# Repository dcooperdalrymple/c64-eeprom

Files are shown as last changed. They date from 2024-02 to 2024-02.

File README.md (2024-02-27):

# C64-EEPROM



Use standard 0.6" DIP EEPROMs in place of a mask rom footprints. Compatible with various mask roms and EEPROMS with solder jumper configuration.

| Top | Bottom |
| --- | --- |
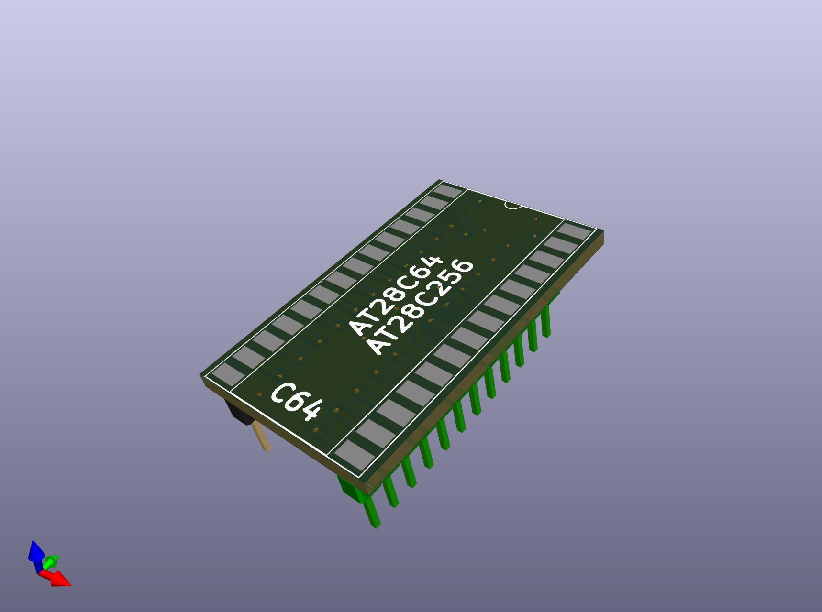
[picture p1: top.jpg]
Top view of the adapter board
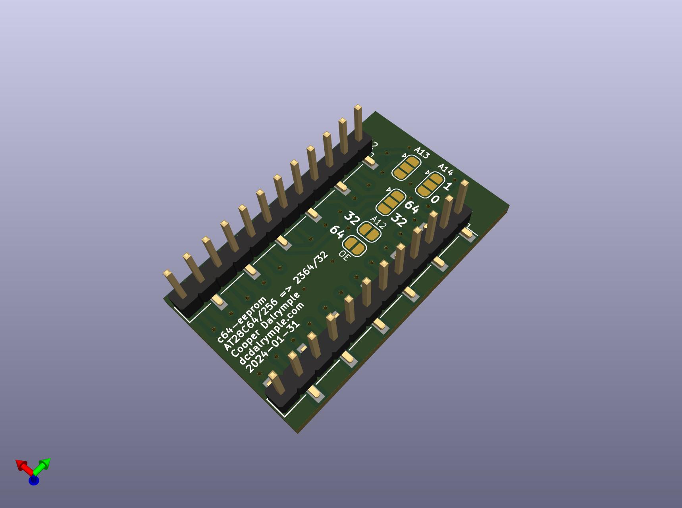
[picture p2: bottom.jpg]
Bottom view of the adapter board
|  |  |

## Compatible ROM ICs

Use the following tables to determine the necessary solder jumper configuration.

### EEPROMs

| EEPROM | Configuration |
| --- | --- |
| AT28C64(B)  | A13 and A14 jumpers can be left unconfigured (NC). |
| AT28C256 | A13 and A14 jumpers can be configured to select 1 of 4 banks. Leave both as "0" (GND) to use first 4/8KB. |

> It is possible to connect switches to the A13 and A14 solder jumper pads to enable quick bank switching with an AT28C256 to select between 4 ROM images. To minimize size and materials, this board does not include this feature by default.

### Mask ROMs

| Mask ROM | Typical Usage | Configuration |
| --- | --- | --- |
| 2364 | C64 Kernal (901227-03) & BASIC (901226-01) ROMs | Solder pad 2 (middle) to pad 1 (arrow) of the 64/32 jumper (the 64 side) and the OE jumper. |
| 2332 | C64 Character ROM (901225-01) | Solder pad 2 (middle) to pad 3 (bottom) of the 64/32 jumper (the 32 side) and the A12 jumper. |

## Materials

This board uses 2 SMD 0.1" pitch pin headers and 1 0.6" wide, 0.1" pitch SMD DIP socket. SMD components were selected to reduce board width. However, standard through hole components can be easily modified to be SMD compatible by bending the socket legs outward and the pin header legs left and right alternating outward.

No other components are necessary as the AT28C64/256 EEPROMS are 5V-compatible and otherwise identical to standard mask roms. Using this board without an IC socket for the EEPROM is possible, but not recommended.

## Programming

EEPROMs are fairly simple and easy to program. They can be programmed using a standard TL866 programmer or any other compatible ROM programmer. A number of other solutions also exist which don't require specialized equipment. Here are a few options using off-the-shelf components:

- [PicoPROM](https://github.com/gfoot/picoprom)
- [32u4-programmer](https://github.com/dcooperdalrymple/32u4-programmer) (a little bit of self-promotion here)
- [Arduino EEPROM programmer](https://github.com/beneater/eeprom-programmer)
- [eeprom-writer](https://github.com/oddblk/eeprom-writer)
- [TommyPROM](https://tomnisbet.github.io/TommyPROM/)

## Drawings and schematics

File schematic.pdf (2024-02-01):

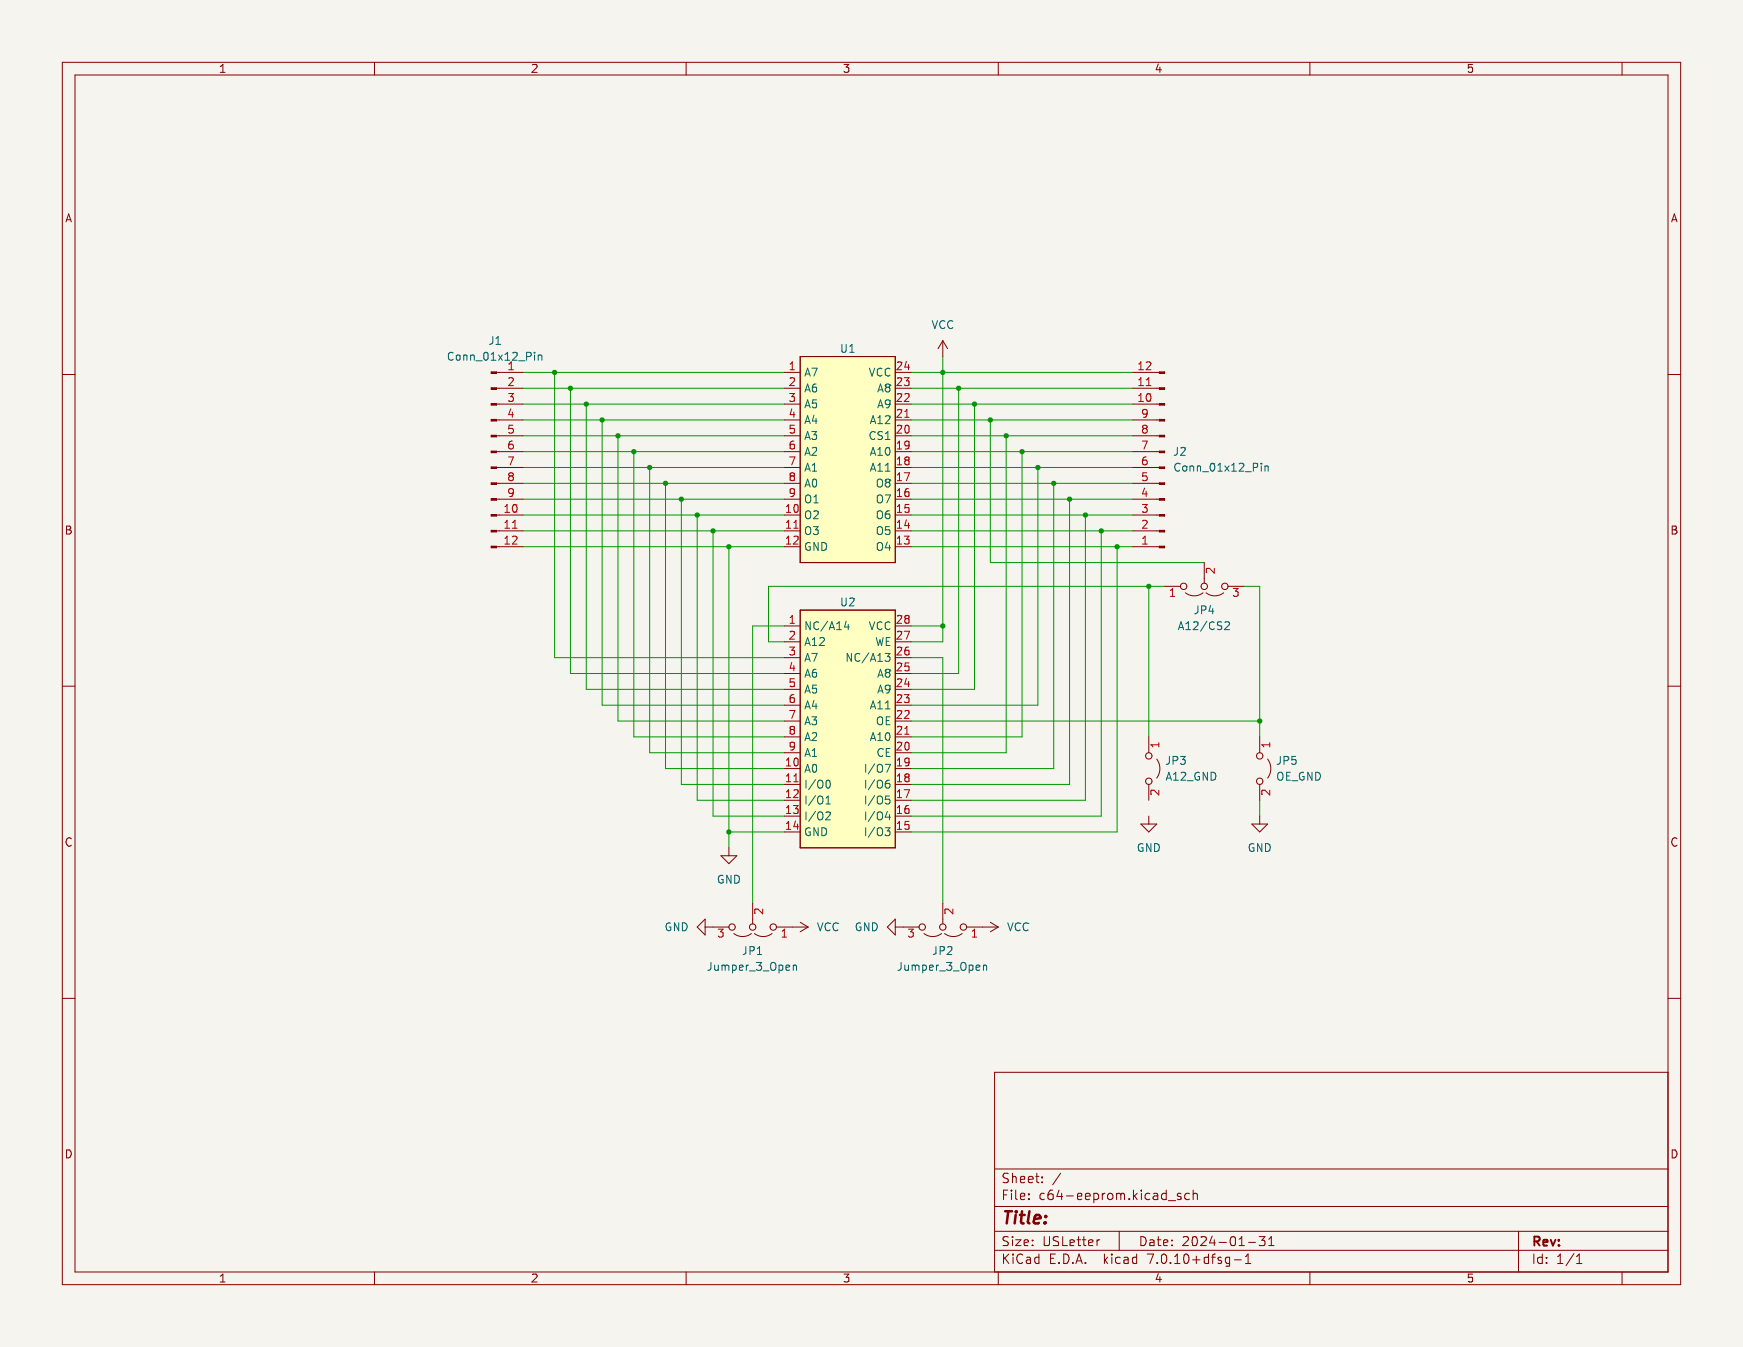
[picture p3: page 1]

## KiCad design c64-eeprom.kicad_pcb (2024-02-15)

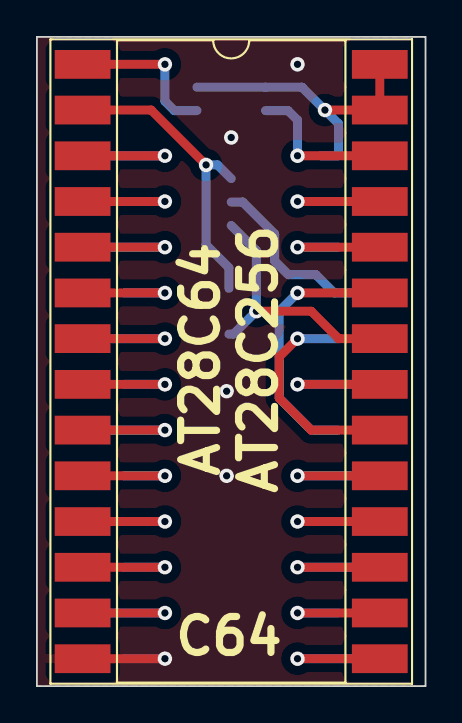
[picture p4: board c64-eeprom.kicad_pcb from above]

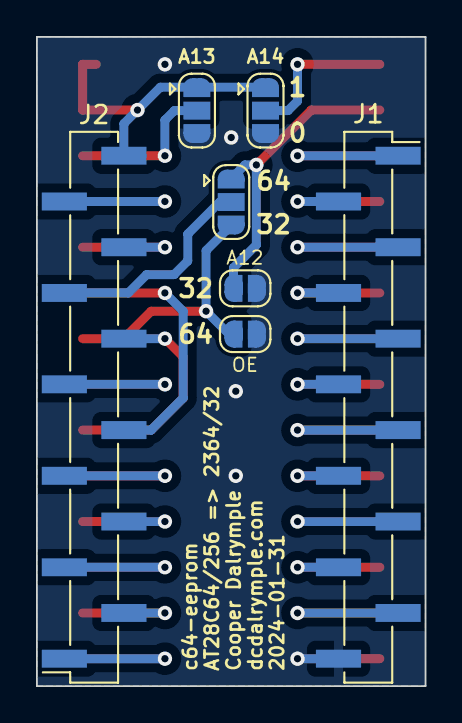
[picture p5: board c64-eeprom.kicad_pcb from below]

Board: 2 copper layers, 21.6 x 36.1 mm, 8 parts (7 on the bottom side), 28 nets.

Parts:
J1, J2: Conn_01x12_Pin; PinHeader_1x12_P2.54mm_Vertical_SMD_Pin1Right
JP1, JP2: Jumper_3_Open; SolderJumper-3_P1.3mm_Open_RoundedPad1.0x1.5mm
JP3: A12_GND; SolderJumper-2_P1.3mm_Open_RoundedPad1.0x1.5mm
JP4: A12/CS2; SolderJumper-3_P1.3mm_Open_RoundedPad1.0x1.5mm
JP5: OE_GND; SolderJumper-2_P1.3mm_Open_RoundedPad1.0x1.5mm
U2: DIP-28_W16.51mm_SMDSocket_LongPads

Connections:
GND: J1.12, JP1.3 (B), JP2.3 (B), JP3.2 (B), JP5.2 (B), U2.14 (GND)
unnamed: J1.1, U2.3 (A7)
unnamed: J1.2, U2.4 (A6)
unnamed: J1.3, U2.5 (A5)
unnamed: J1.4, U2.6 (A4)
unnamed: J1.5, U2.7 (A3)
unnamed: J1.6, U2.8 (A2)
unnamed: J1.7, U2.9 (A1)
unnamed: J1.8, U2.10 (A0)
unnamed: J1.9, U2.11 (I/O0)
unnamed: J1.10, U2.12 (I/O1)
unnamed: J1.11, U2.13 (I/O2)
unnamed: J2.1, U2.15 (I/O3)
unnamed: J2.2, U2.16 (I/O4)
unnamed: J2.3, U2.17 (I/O5)
unnamed: J2.4, U2.18 (I/O6)
unnamed: J2.5, U2.19 (I/O7)
unnamed: J2.6, U2.23 (A11)
unnamed: J2.7, U2.21 (A10)
unnamed: J2.8, U2.20 (CE)
unnamed: J2.9, JP4.2 (C)
unnamed: J2.10, U2.24 (A9)
unnamed: J2.11, U2.25 (A8)
unnamed: JP1.2 (C), U2.1 (NC/A14)
unnamed: JP2.2 (C), U2.26 (NC/A13)
unnamed: JP3.1 (A), JP4.1 (A), U2.2 (A12)
unnamed: JP4.3 (B), JP5.1 (A), U2.22 (OE)
VCC: J2.12, JP1.1 (A), JP2.1 (A), U2.27 (WE), U2.28 (VCC)

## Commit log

2024-02-01 Initial design.
    [c64-eeprom.kicad_pcb, c64-eeprom.kicad_sch]
2024-02-01 Added schematic PDF
    [c64-eeprom.kicad_sch]
2024-02-01 Added silkscreen to top to indicate compatible eeproms.
    [c64-eeprom.kicad_pcb]
2024-02-01 Updated gitignore to remove generated gerber files.
2024-02-15 Fix disconnected jumper pad, A12.
    [c64-eeprom.kicad_pcb, c64-eeprom.kicad_sch]
